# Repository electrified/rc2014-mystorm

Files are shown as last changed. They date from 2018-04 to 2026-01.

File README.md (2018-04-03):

## Board to interface 3.3v FPGA board with RC2014

BOM

5x SN74LVCC3245ADW

LD1117S33TR

100nF 0805 capacitors

10μF 0805 capacitors

OE low = enable
dir rc ->fpga

objcopy -Iihex -Obinary nascom32k_hexloadr.hex out.bin

sigrok-cli --driver saleae-logic16 --config samplerate=20Mhz --channels 0=D0,1=D1,2=D2,3=D3,4=D4,5=D5,6=D6,7=D7,9=RD,10=WR,11=MREQ,13=M1 --samples 1M --output-file z80-fpga

Silkscreen blunders

On the fpga connector, silscreen for M1 and RD should be swapped

https://bitbucket.org/gdevic/a-z80/src/6d6bd4838181ea9e088e6c1f7c68e4f11ce58183/host/basic_de1/basic_de1_fpga.sv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

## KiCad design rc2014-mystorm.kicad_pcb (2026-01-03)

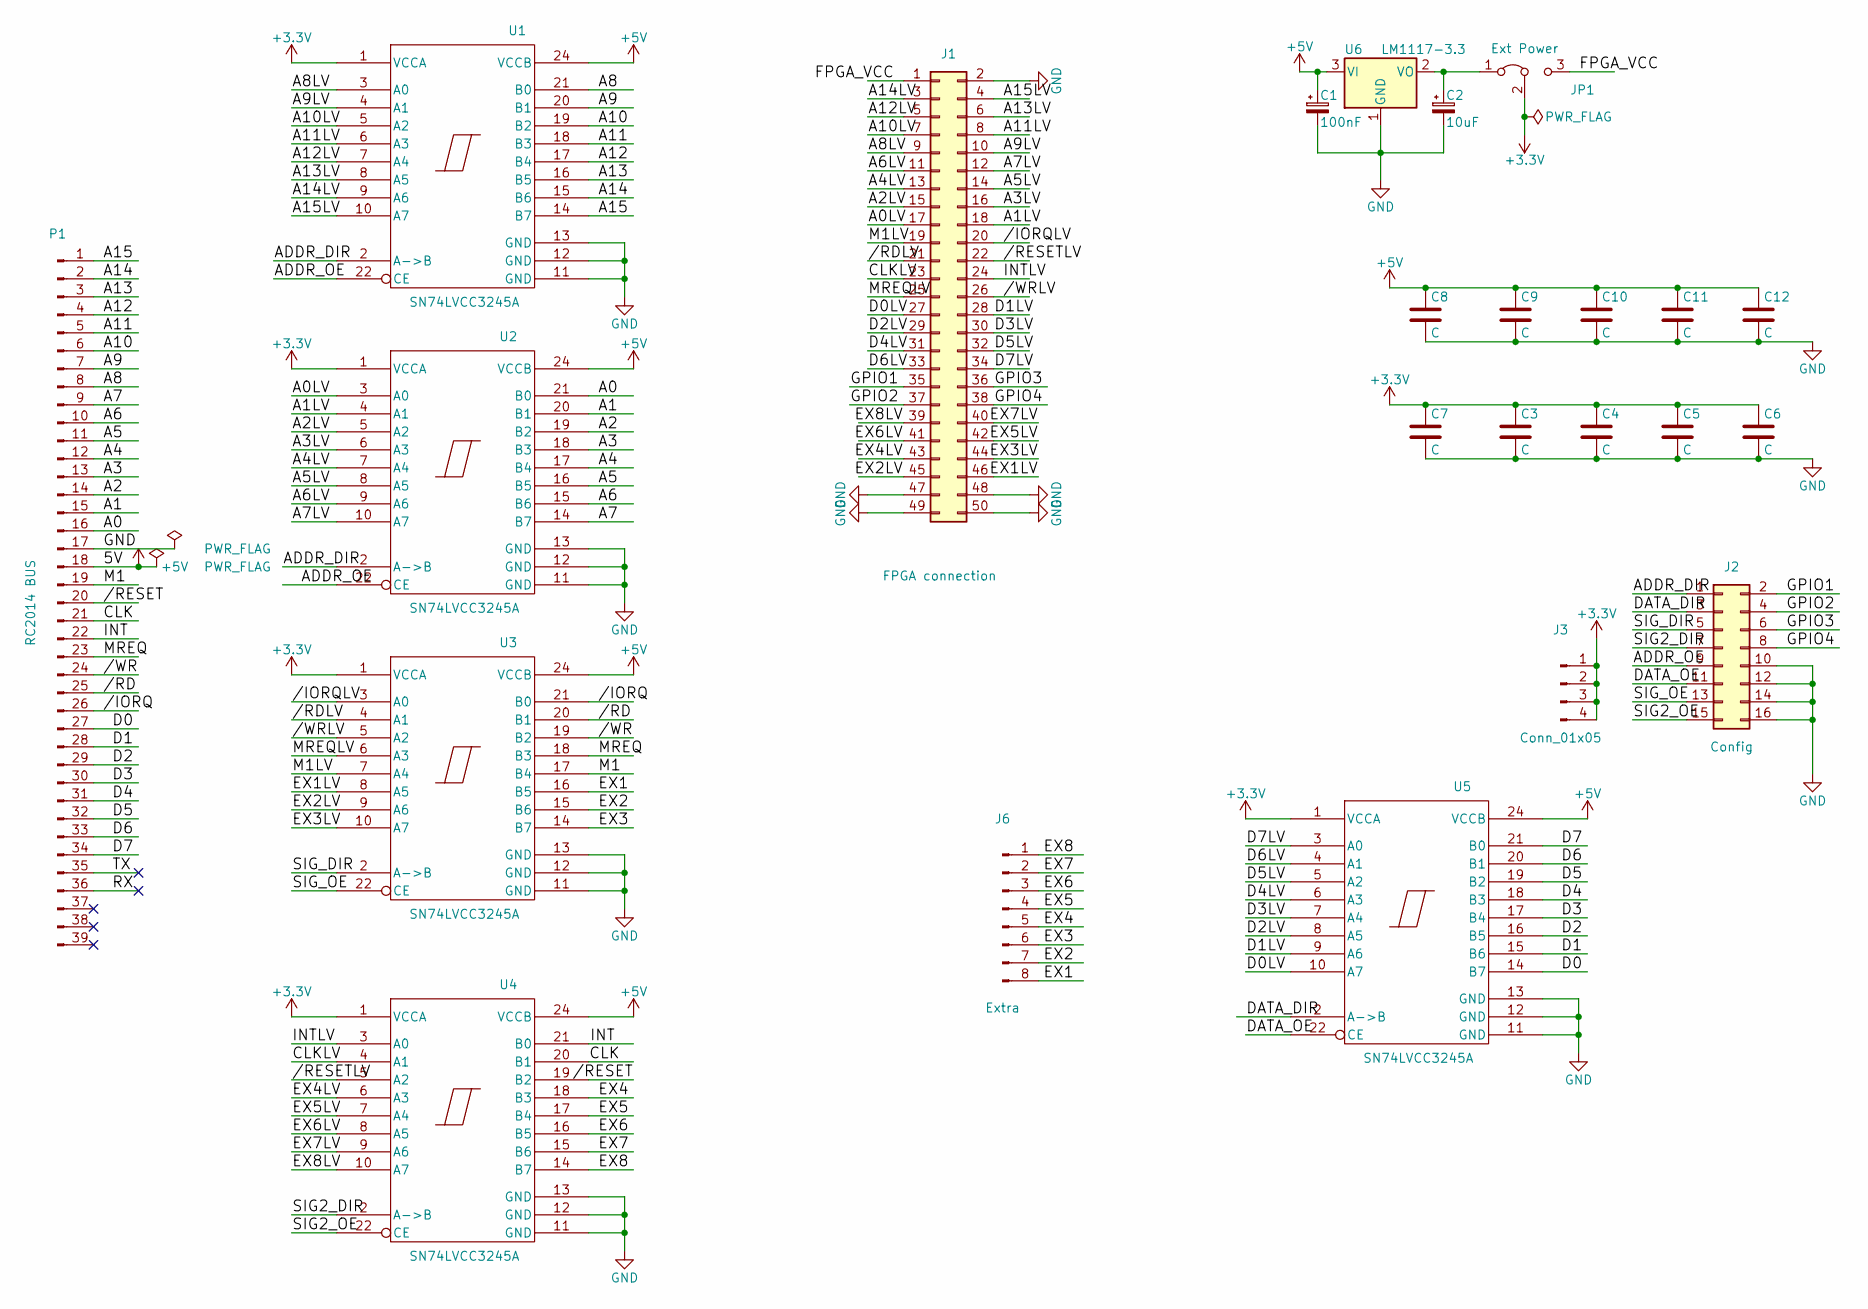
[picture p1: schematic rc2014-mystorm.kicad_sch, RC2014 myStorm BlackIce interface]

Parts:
C1: 100nF; C_0805_HandSoldering
C2: 10uF; C_0805_HandSoldering
C3, C4, C5, C6, C7, C8, C9, C10, C11, C12: C; C_0805_HandSoldering
J1: FPGA connection; IDC-Header_2x25_Pitch2.54mm_Straight
J2: Config; Pin_Header_Straight_2x08_Pitch2.54mm
J3: Conn_01x05; Pin_Header_Straight_1x04_Pitch2.54mm
J6: Extra; Pin_Header_Straight_1x08_Pitch2.54mm
JP1: Ext Power; Pin_Header_Straight_1x03_Pitch2.54mm
P1: RC2014 BUS; Pin_Header_Straight_1x39_Pitch2.54mm_NoSilk
U1, U2, U3, U4, U5: SN74LVCC3245A; SOIC-24W_7.5x15.4mm_Pitch1.27mm
U6: LM1117-3.3; SOT-223-3_TabPin2

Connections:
+3.3V: C3.1, C4.1, C5.1, C6.1, C7.1, J3.1, J3.2, J3.3, J3.4, JP1.2 (C), U1.1 (VCCA), U2.1 (VCCA), U3.1 (VCCA), U4.1 (VCCA), U5.1 (VCCA)
+5V: C1.1, C8.1, C9.1, C10.1, C11.1, C12.1, P1.18, U1.24 (VCCB), U2.24 (VCCB), U3.24 (VCCB), U4.24 (VCCB), U5.24 (VCCB), U6.3 (VI)
/A0: P1.16, U2.21 (B0)
/A0LV: J1.17, U2.3 (A0)
/A1: P1.15, U2.20 (B1)
/A1LV: J1.18, U2.4 (A1)
/A2: P1.14, U2.19 (B2)
/A2LV: J1.15, U2.5 (A2)
/A3: P1.13, U2.18 (B3)
/A3LV: J1.16, U2.6 (A3)
/A4: P1.12, U2.17 (B4)
/A4LV: J1.13, U2.7 (A4)
/A5: P1.11, U2.16 (B5)
/A5LV: J1.14, U2.8 (A5)
/A6: P1.10, U2.15 (B6)
/A6LV: J1.11, U2.9 (A6)
/A7: P1.9, U2.14 (B7)
/A7LV: J1.12, U2.10 (A7)
/A8: P1.8, U1.21 (B0)
/A8LV: J1.9, U1.3 (A0)
/A9: P1.7, U1.20 (B1)
/A9LV: J1.10, U1.4 (A1)
/A10: P1.6, U1.19 (B2)
/A10LV: J1.7, U1.5 (A2)
/A11: P1.5, U1.18 (B3)
/A11LV: J1.8, U1.6 (A3)
/A12: P1.4, U1.17 (B4)
/A12LV: J1.5, U1.7 (A4)
/A13: P1.3, U1.16 (B5)
/A13LV: J1.6, U1.8 (A5)
/A14: P1.2, U1.15 (B6)
/A14LV: J1.3, U1.9 (A6)
/A15: P1.1, U1.14 (B7)
/A15LV: J1.4, U1.10 (A7)
/ADDR_DIR: J2.1, U1.2 (A->B), U2.2 (A->B)
/ADDR_OE: J2.9, U1.22 (CE), U2.22 (CE)
/CLK: P1.21, U4.20 (B1)
/CLKLV: J1.23, U4.4 (A1)
/D0: P1.27, U5.14 (B7)
/D0LV: J1.27, U5.10 (A7)
/D1: P1.28, U5.15 (B6)
/D1LV: J1.28, U5.9 (A6)
/D2: P1.29, U5.16 (B5)
/D2LV: J1.29, U5.8 (A5)
/D3: P1.30, U5.17 (B4)
/D3LV: J1.30, U5.7 (A4)
/D4: P1.31, U5.18 (B3)
/D4LV: J1.31, U5.6 (A3)
/D5: P1.32, U5.19 (B2)
/D5LV: J1.32, U5.5 (A2)
/D6: P1.33, U5.20 (B1)
/D6LV: J1.33, U5.4 (A1)
/D7: P1.34, U5.21 (B0)
/D7LV: J1.34, U5.3 (A0)
/DATA_DIR: J2.3, U5.2 (A->B)
/DATA_OE: J2.11, U5.22 (CE)
/EX1: J6.8, U3.16 (B5)
/EX1LV: J1.46, U3.8 (A5)
/EX2: J6.7, U3.15 (B6)
/EX2LV: J1.45, U3.9 (A6)
/EX3: J6.6, U3.14 (B7)
/EX3LV: J1.44, U3.10 (A7)
/EX4: J6.5, U4.18 (B3)
/EX4LV: J1.43, U4.6 (A3)
/EX5: J6.4, U4.17 (B4)
/EX5LV: J1.42, U4.7 (A4)
/EX6: J6.3, U4.16 (B5)
/EX6LV: J1.41, U4.8 (A5)
/EX7: J6.2, U4.15 (B6)
/EX7LV: J1.40, U4.9 (A6)
/EX8: J6.1, U4.14 (B7)
/EX8LV: J1.39, U4.10 (A7)
/FPGA_VCC: J1.1, JP1.3 (B)
/GPIO1: J1.35, J2.2
/GPIO2: J1.37, J2.4
/GPIO3: J1.36, J2.6
/GPIO4: J1.38, J2.8
/INT: P1.22, U4.21 (B0)
/INTLV: J1.24, U4.3 (A0)
/M1: P1.19, U3.17 (B4)
/M1LV: J1.19, U3.7 (A4)
/MREQ: P1.23, U3.18 (B3)
/MREQLV: J1.25, U3.6 (A3)
/RX: P1.36
/SIG2_DIR: J2.7, U4.2 (A->B)
/SIG2_OE: J2.15, U4.22 (CE)
/SIG_DIR: J2.5, U3.2 (A->B)
/SIG_OE: J2.13, U3.22 (CE)
/TX: P1.35
//IORQ: P1.26, U3.21 (B0)
//IORQLV: J1.20, U3.3 (A0)
//RD: P1.25, U3.20 (B1)
//RDLV: J1.21, U3.4 (A1)
//RESET: P1.20, U4.19 (B2)
//RESETLV: J1.22, U4.5 (A2)
//WR: P1.24, U3.19 (B2)
//WRLV: J1.26, U3.5 (A2)
GND: C1.2, C2.2, C3.2, C4.2, C5.2, C6.2, C7.2, C8.2, C9.2, C10.2, C11.2, C12.2, J1.2, J1.47, J1.48, J1.49, J1.50, J2.10, J2.12, J2.14, J2.16, P1.17, U1.11 (GND), U1.12 (GND), U1.13 (GND), U2.11 (GND), U2.12 (GND), U2.13 (GND), U3.11 (GND), U3.12 (GND), U3.13 (GND), U4.11 (GND), U4.12 (GND), U4.13 (GND), U5.11 (GND), U5.12 (GND), U5.13 (GND), U6.1 (GND)
unnamed: C2.1, JP1.1 (A), U6.2 (VO)

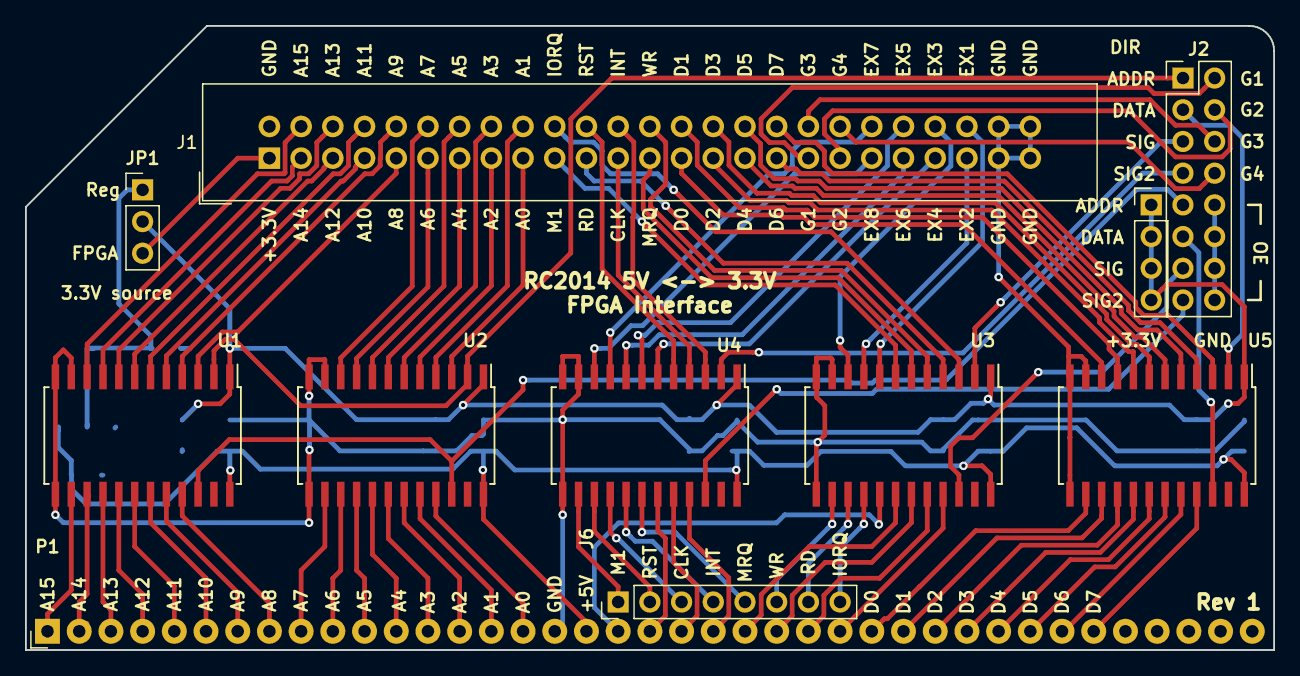
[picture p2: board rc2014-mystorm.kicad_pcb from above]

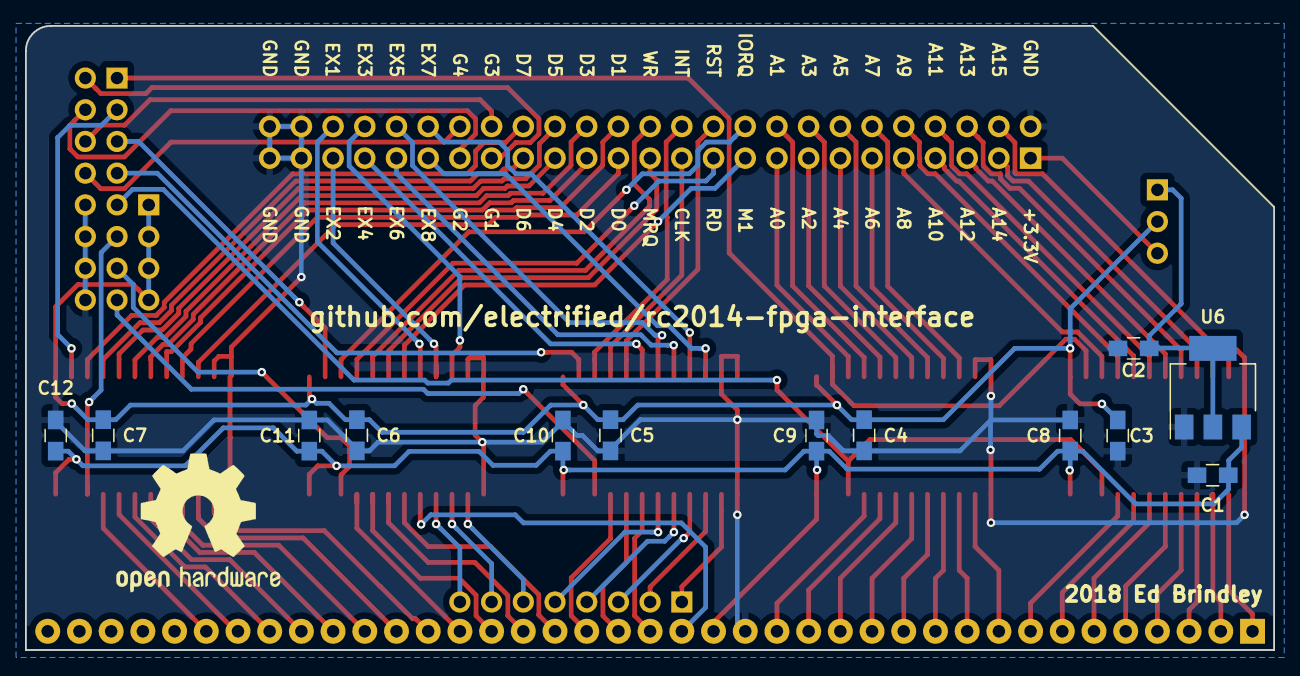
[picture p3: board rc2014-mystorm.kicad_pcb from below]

Board: 2 copper layers, 100.0 x 50.0 mm, 24 parts (13 on the bottom side), 97 nets.

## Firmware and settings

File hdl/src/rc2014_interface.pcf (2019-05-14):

set_io LED1 71 #P52
#set_io LED2 67 #P53
#set_io LED3 #P54
#set_io LED4 #P55

set_io BUT1 63 #B1
set_io BUT2 64 #B1

set_io uart_tx 85 # rd0

#pmod 4
set_io A[14] 96 #P15
set_io A[12] 98 #P14
set_io A[10] 101 #P13
set_io A[8] 104 #P12

#pmod 3
set_io A[15] 97 #P11
set_io A[13] 99 #P10
set_io A[11] 102 #P9
set_io A[9] 105 #P8

#pmod 6
set_io A[6] 106 #P23
set_io A[4] 110 #P22
set_io A[2] 113 #P21
set_io A[0] 144 #P20

#pmod 5
set_io A[7] 107 #P19
set_io A[5] 112 #P18
set_io A[3] 114 #P17
set_io A[1] 143 #P16

#pmod 8
set_io M1 3 #P31
set_io RD 4 #P30
set_io CLK 7 #P29
set_io MRQ 8 #P28

#pmod 7
set_io IORQ 1 #P27
set_io RST 2 #P26
set_io INT 9 #P25
set_io WR 10 #P24

#pmod 10
set_io D[0] 11 #P39
set_io D[2] 12 #P38
set_io D[4] 17 #P37
set_io D[6] 18 #P36

#pmod 9
set_io D[1] 15 #P35
set_io D[3] 16 #P34
set_io D[5] 19 #P33
set_io D[7] 20 #P32

#pmod 12
set_io ADDR_DIR 25 #P47 #this is now data OE was ADDR_DIR
set_io DATA_DIR 26 #P46
#set_io EX7 31 #P45
#set_io EX[5] 32 #P44

#pmod 11
set_io SIG_DIR 21 #P43
set_io SIG2_DIR 22 #P42
#set_io EX[6] 33 #P41
#set_io EX[4] 34 #P40

#set_io EX[3]
#set_io EX[2]
#set_io EX[1]
#set_io EX[0]


# # SRAM
# set_io ADR[0] 137
# set_io ADR[1] 138
# set_io ADR[2] 139
# set_io ADR[3] 141
# set_io ADR[4] 142
# set_io ADR[5] 42
# set_io ADR[6] 43
# set_io ADR[7] 44
# set_io ADR[8] 73
# set_io ADR[9] 74
# set_io ADR[10] 75
# set_io ADR[11] 76
# set_io ADR[12] 115
# set_io ADR[13] 116
# set_io ADR[14] 117
# set_io ADR[15] 118
# set_io ADR[16] 119
# set_io ADR[17] 78
# #set_io ADR[18] 62

# set_io DAT[0] 135
# set_io DAT[1] 134
# set_io DAT[2] 130
# set_io DAT[3] 128
# set_io DAT[4] 125
# set_io DAT[5] 124
# set_io DAT[6] 122
# set_io DAT[7] 121
# #set_io DAT[8] 61
# #set_io DAT[9] 60
# #set_io DAT[10] 56
# #set_io DAT[11] 55
# #set_io DAT[12] 52
# #set_io DAT[13] 49
# #set_io DAT[14] 48
# #set_io DAT[15] 47

# set_io RAMOE_b 45
# set_io RAMWE_b 120
# set_io RAMCS_b 136

# Onboard 12Mhz oscillator
set_io fpga_clk 129

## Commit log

2017-09-18 realise layout blunder
    [rc2014-mystorm.kicad_pcb]
2018-01-23 further SMT WIP
    [rc2014-mystorm.kicad_pcb, rc2014-mystorm.sch]
2018-02-10 Remove unused files and update readme
    [rc2014-mystorm.sch]
2018-02-19 gerbers as manuf'd and begginings of hdl
    [rc2014-mystorm.kicad_pcb, rc2014-mystorm.sch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]
2018-04-04 Fix PCB labels and more WIP
    [rc2014-mystorm.kicad_pcb]
2019-05-01 upgrade to kicad 5, commit of hdl
    [rc2014-mystorm-2019-04-28-20-02-34.sch, rc2014-mystorm.kicad_pcb, rc2014-mystorm.sch]
2019-05-13 convert to nextpnr
    [rc2014-mystorm.kicad_pcb]
2026-01-03 resave with kicad 9 and tidy up - no attempt made to update to new component libraries
    [rc2014-mystorm-2019-04-28-20-02-34.sch, rc2014-mystorm.kicad_pcb, rc2014-mystorm.kicad_sch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]
